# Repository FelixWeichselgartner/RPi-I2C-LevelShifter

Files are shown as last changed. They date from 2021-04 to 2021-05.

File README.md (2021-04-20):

Raspberry Pi I²C Level-Shifter
==============================

A PiHAT for converting the Raspberry Pi I²C Signals from 3.3V levels to 5V levels, which is usefull if you want to interface with I²C-components that use 5V voltage levels. The project aims to save time in wiring up an external level-shifter and just plug a shield on top of the gpio pins of the Raspberry Pi.

## Schematics, Layout

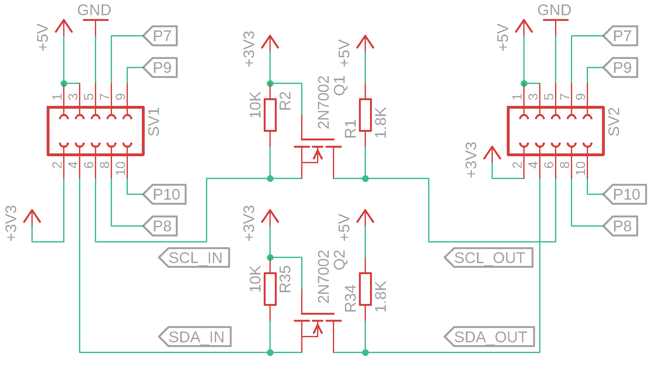
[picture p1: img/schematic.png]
schematic

<br>

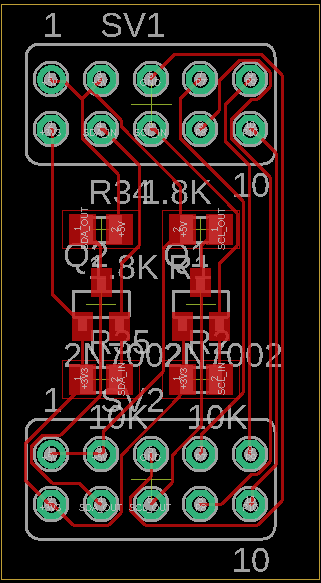
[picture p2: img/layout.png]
layout

<br>

## Application

This is how the module is supposed to be used:

On Raspberry Pi 3B+:

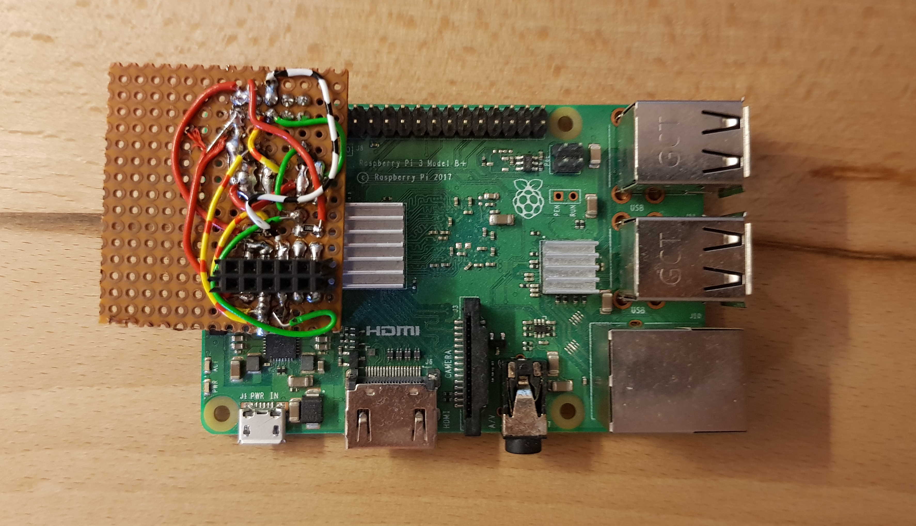
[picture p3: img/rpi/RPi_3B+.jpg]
3b+

<br>

On Raspberry Pi Compute Module 4 IO Board:

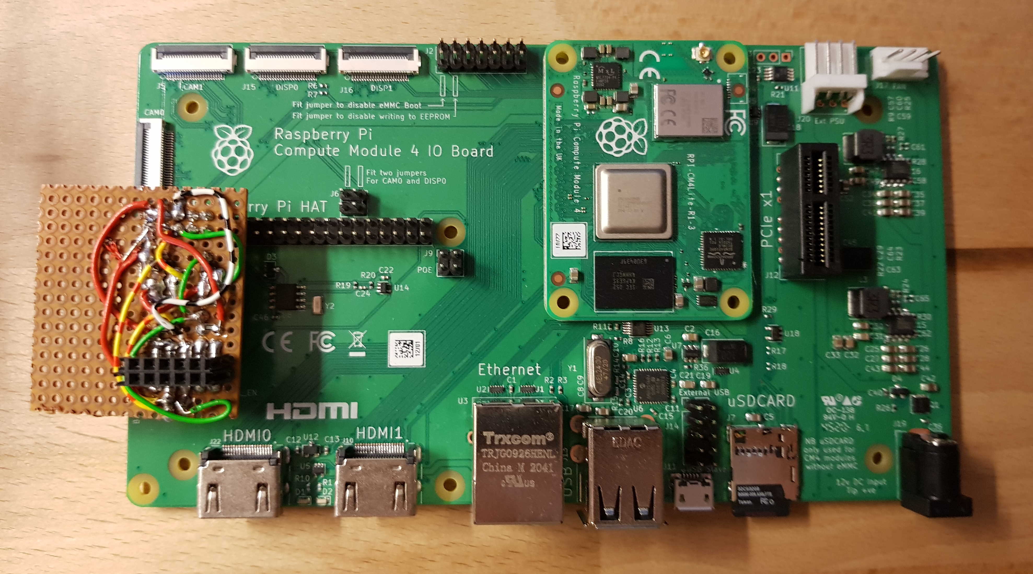
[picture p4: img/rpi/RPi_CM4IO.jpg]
cm4

<br>

## Testing

I tested the pcb, however I hand-soldered everything (which I can definitely not recommend). Everything is soldered exactly like in the schematic, even though I placed some parts differently.

Here is how my prototype looks like:

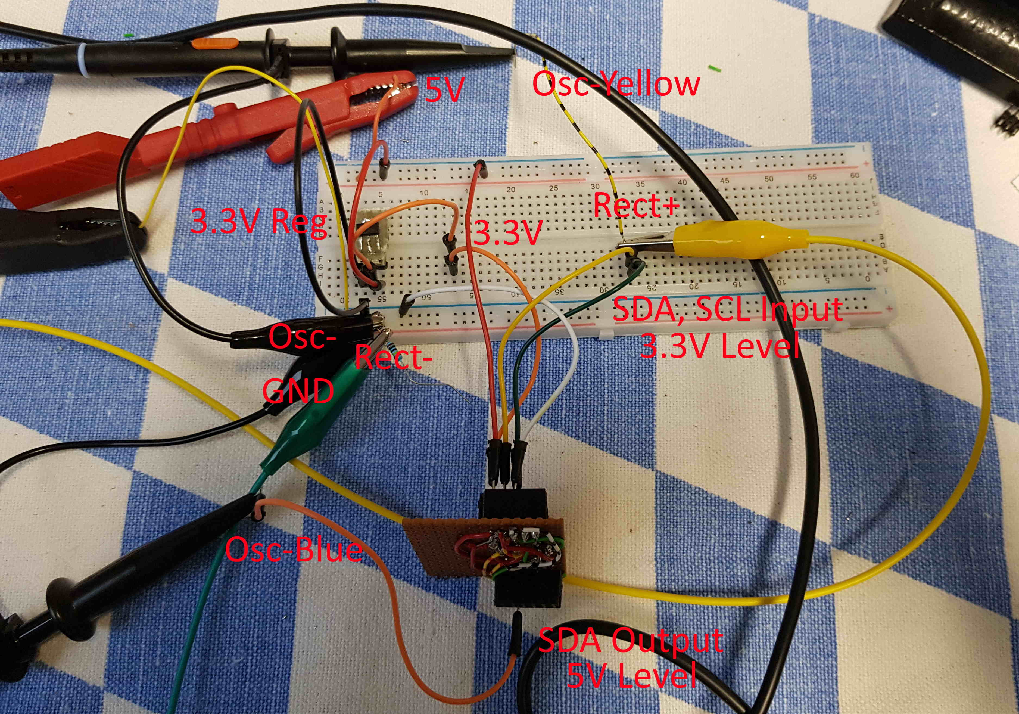
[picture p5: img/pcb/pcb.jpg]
pcb

<br>

<br>
And here are my oscilloscope measurements on level shifting a rectangular pulse with the following frequencies:

40kHz:

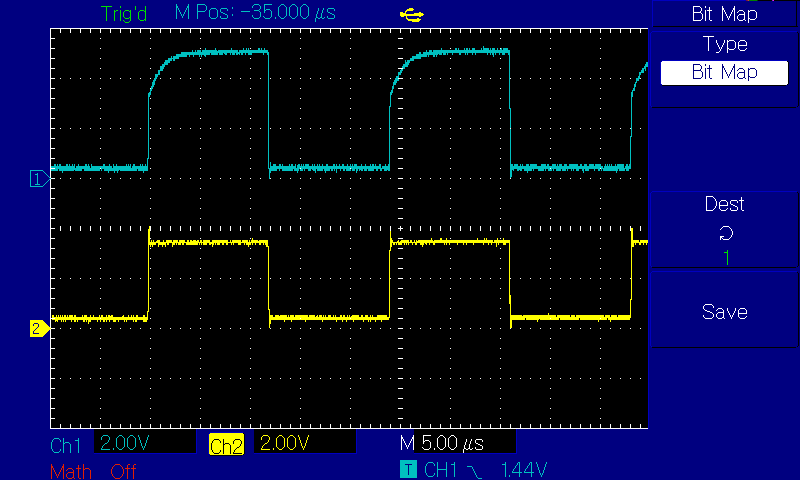
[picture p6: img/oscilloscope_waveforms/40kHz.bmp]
osci_40kHz

<br>

200kHz:

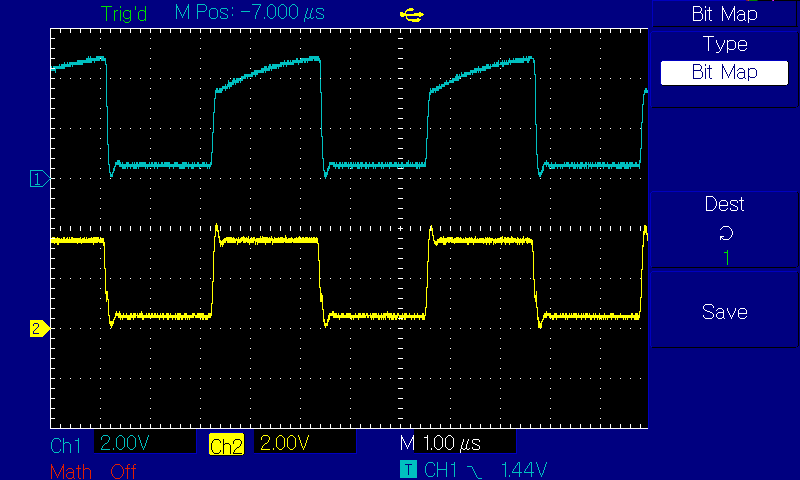
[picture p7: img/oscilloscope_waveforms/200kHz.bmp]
osci_200kHz

<br>

500kHz (from here on it doesn't seem to be able to reach the full 5V):

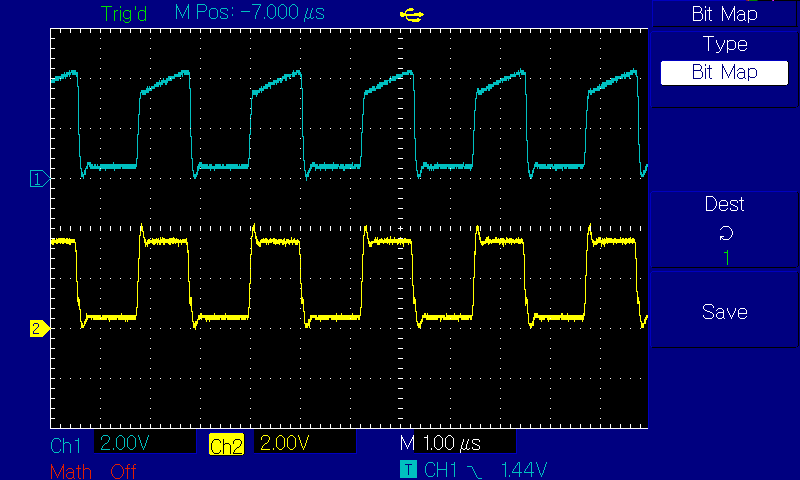
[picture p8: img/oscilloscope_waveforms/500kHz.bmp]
osci_500kHz

<br>

This behaviours is confirmed by simulation.

And here a screenshot of the included LT-Spice simulation:

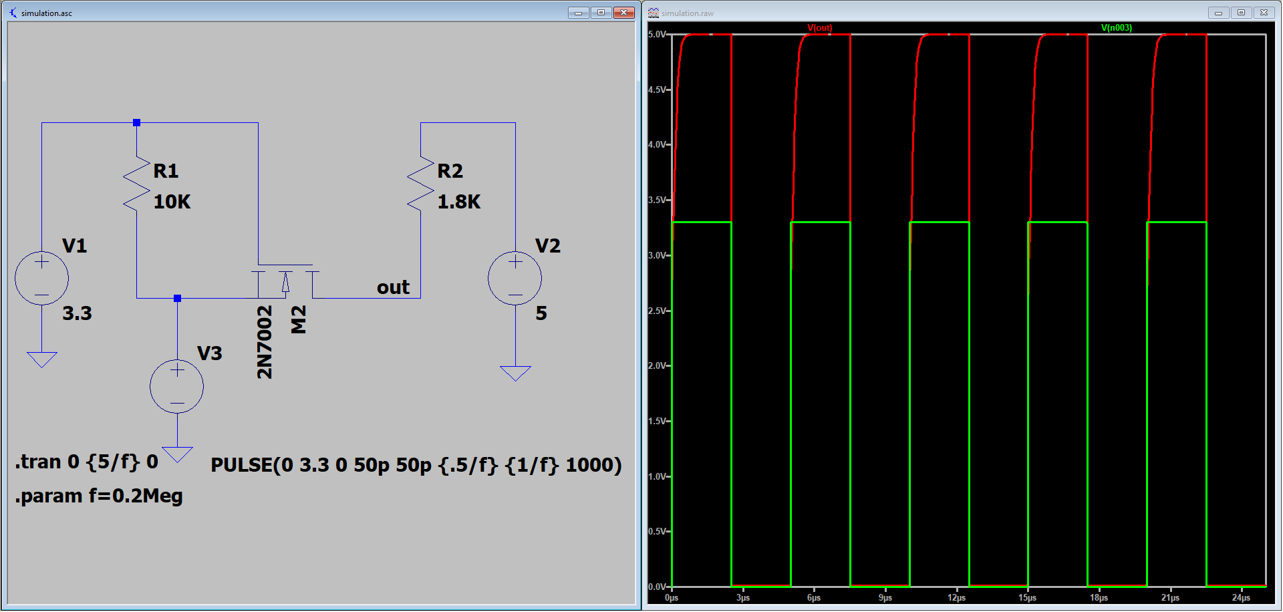
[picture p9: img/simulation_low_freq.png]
simulation_low_freq

<br>

And here a simulation of high frequencies. This shows (as the real graph above) that the mosfet is too slow for MHz frequencies. Replace the mosfet with a faster one if you have to a high frequency application.

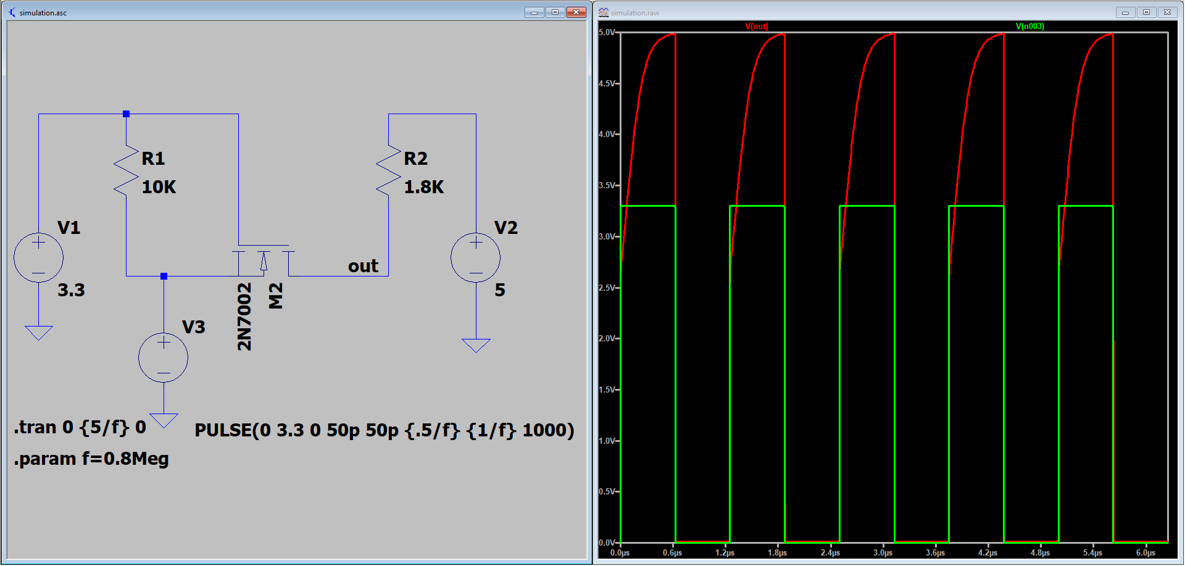
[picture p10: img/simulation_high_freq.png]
simulation_high_freq

<br>

## Dependencies

2N7002 MOSFET library (lbr/transistors_gaui.lbr):
* http://eagle.autodesk.com/eagle/download/1129

## License

The project is licensed under the MIT-License. For further information see `LICENSE.md`.

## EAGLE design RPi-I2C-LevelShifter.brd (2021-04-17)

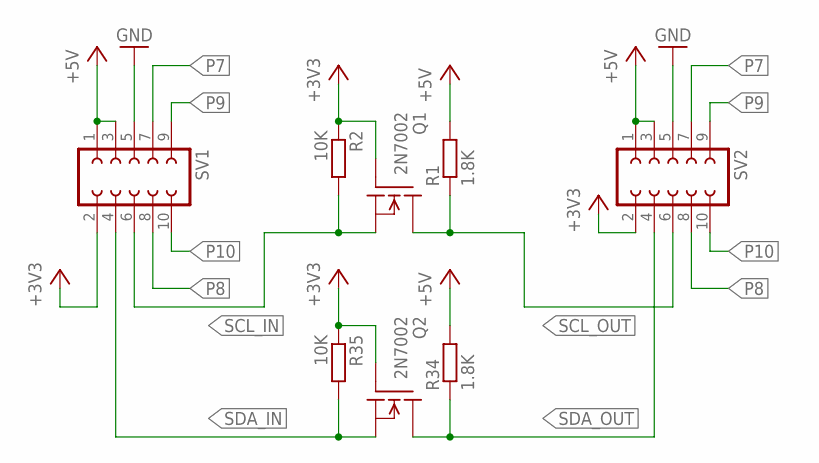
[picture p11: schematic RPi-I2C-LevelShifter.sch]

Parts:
Q1, Q2: 2N7002; SOT23
R1, R34: 1.8K; R0805
R2, R35: 10K; R0805
SV1, SV2: FE05-2

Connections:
+3V3: Q1.1 (G), Q2.1 (G), R2.1, R35.1, SV1.2, SV2.2
+5V: R1.2, R34.2, SV1.1, SV1.3, SV2.1, SV2.3
GND: SV1.5, SV2.5
P7: SV1.7, SV2.7
P8: SV1.8, SV2.8
P9: SV1.9, SV2.9
P10: SV1.10, SV2.10
SCL_IN: Q1.2 (S), R2.2, SV1.6
SCL_OUT: Q1.3 (D), R1.1, SV2.6
SDA_IN: Q2.2 (S), R35.2, SV1.4
SDA_OUT: Q2.3 (D), R34.1, SV2.4

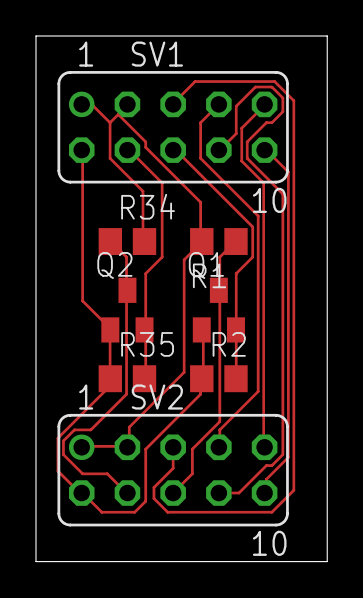
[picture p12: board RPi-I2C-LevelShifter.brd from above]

Board: 2 copper layers, 16.2 x 29.2 mm, 8 parts (0 on the bottom side), 11 nets.

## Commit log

2021-04-14 fixed error
    [RPi-I2C-LevelShifter.brd, RPi-I2C-LevelShifter.sch]
2021-04-14 optimized layout
    [RPi-I2C-LevelShifter.brd]
2021-04-17 added simulation; improved layout
    [RPi-I2C-LevelShifter.brd]
